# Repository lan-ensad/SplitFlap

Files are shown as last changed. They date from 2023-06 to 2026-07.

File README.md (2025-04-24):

# SplitFlap

Project : 

Installation for photographer [exhibition Isabelle Le Minh](https://galeriegaillard.com/exhibitions/206-isabelle-le-minh-postlude/overview/). Design & production by Olivier Bienz and Martin De Bie for six machines.

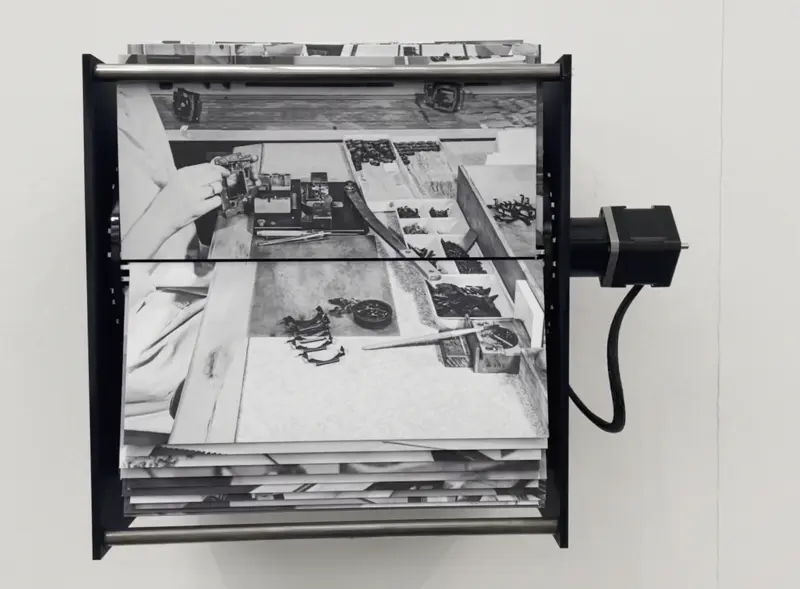
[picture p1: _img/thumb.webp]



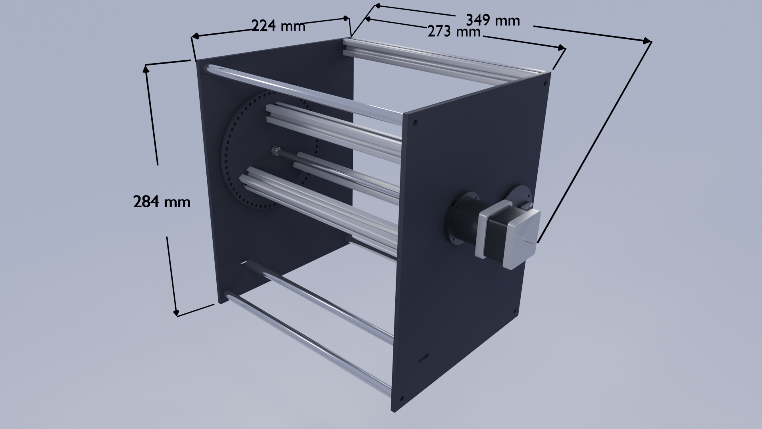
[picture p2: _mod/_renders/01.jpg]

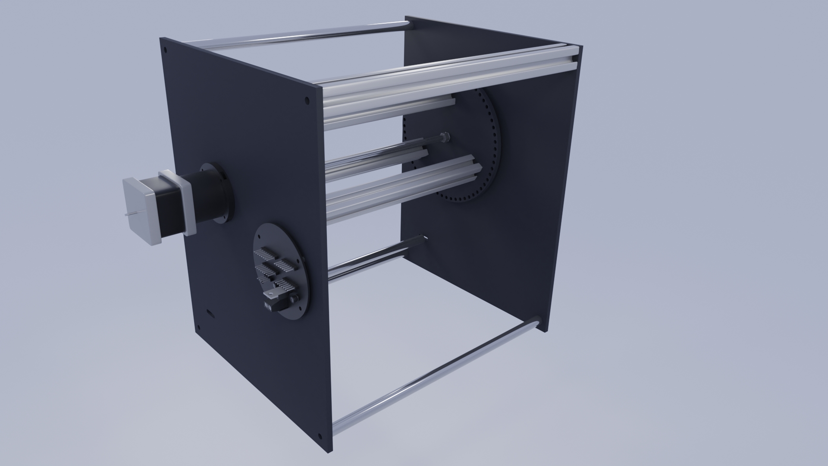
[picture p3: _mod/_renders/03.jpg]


## list

plans : .dxf et .svg \
`_mod/_exports/_plans`

pcb design : schematic, layout and gerber \
`_pcb/split_falp`

programme : \
two easy code to set motorSpeed and calibrate steps.

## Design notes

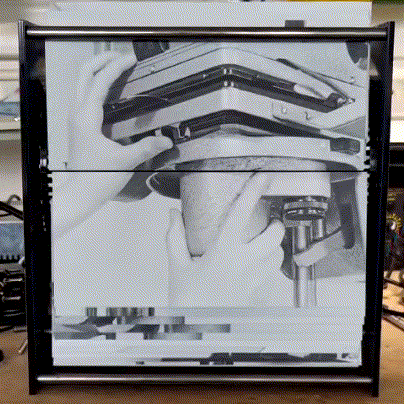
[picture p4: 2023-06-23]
output.gif

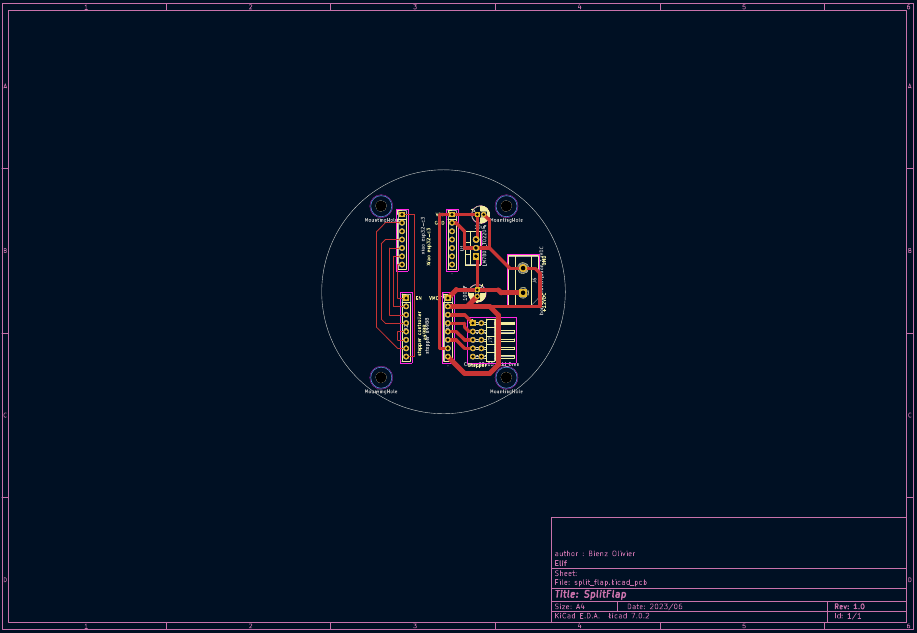
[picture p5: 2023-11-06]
pcb.png

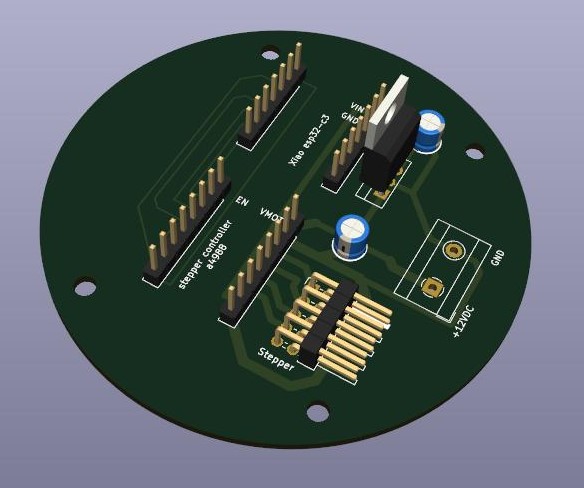
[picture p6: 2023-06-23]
_pcb/split_flap.jpg

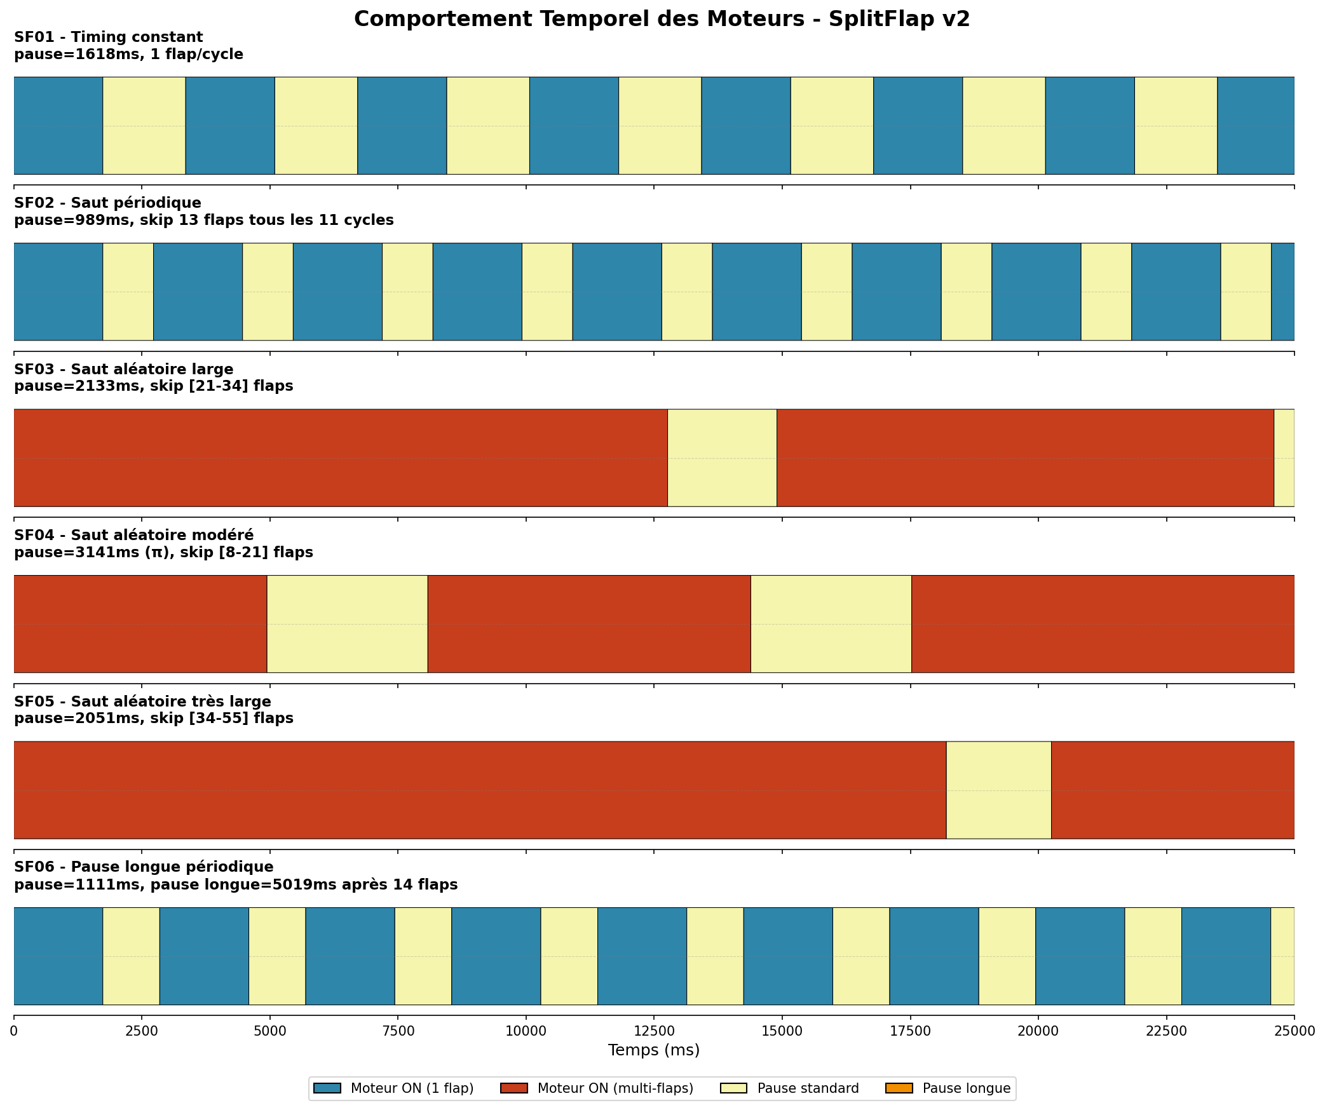
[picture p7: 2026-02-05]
_code/_v2/motor_timing_diagram.png

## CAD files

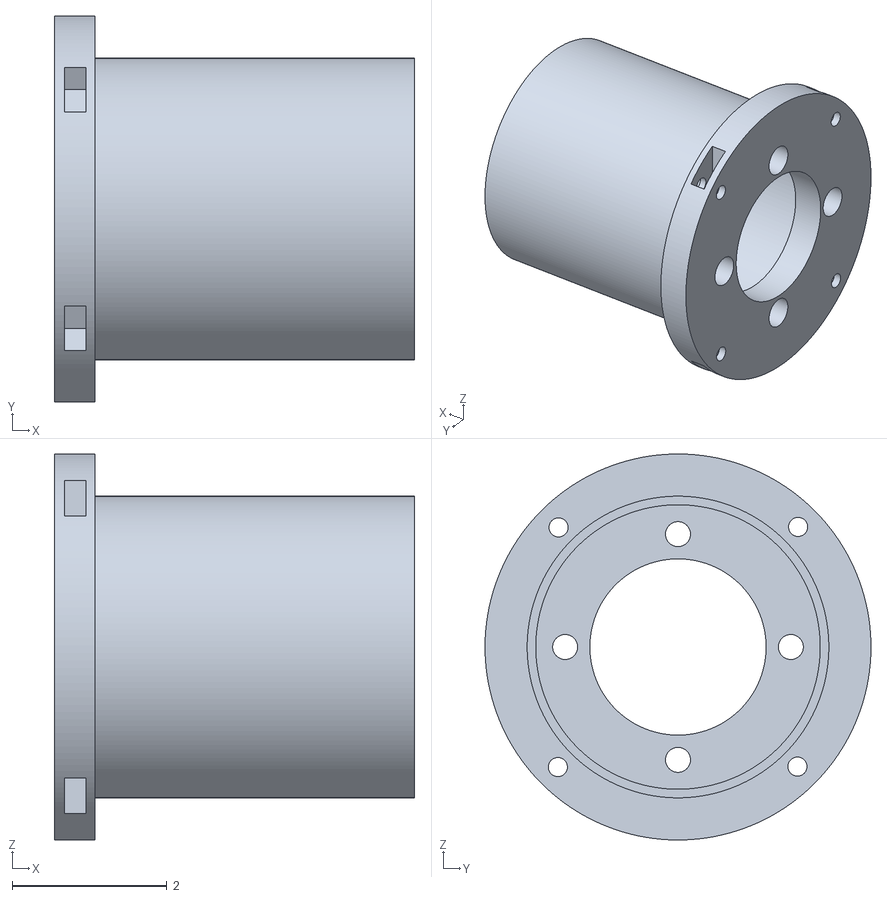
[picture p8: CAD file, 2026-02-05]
_mod/_exports/_3dprint/motor_mount.stl
4.65 x 4.98 x 4.98

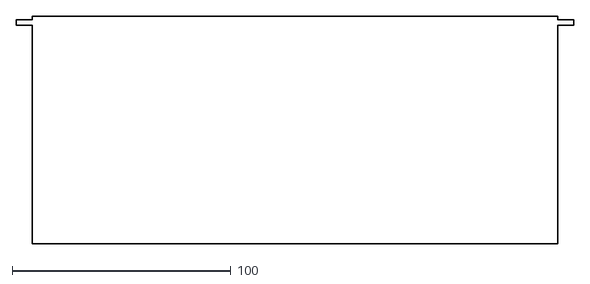
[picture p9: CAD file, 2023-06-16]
_mod/_exports/_plans/dxf/flap.dxf
255.0 x 104.0

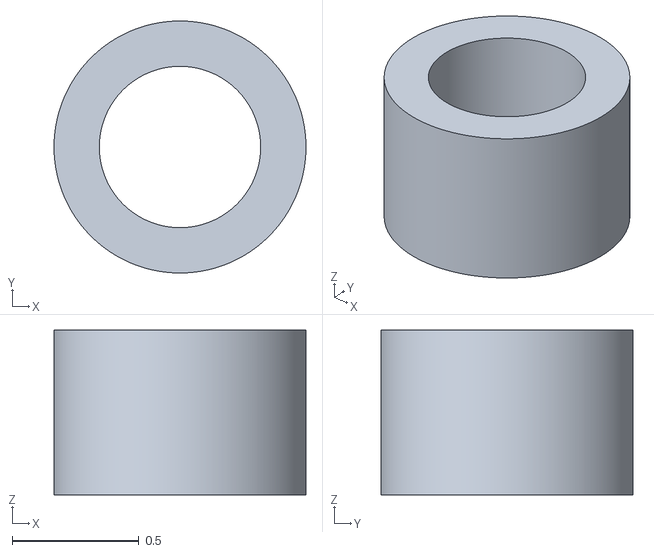
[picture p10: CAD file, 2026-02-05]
_mod/appendice.stl
0.994 x 0.994 x 0.65

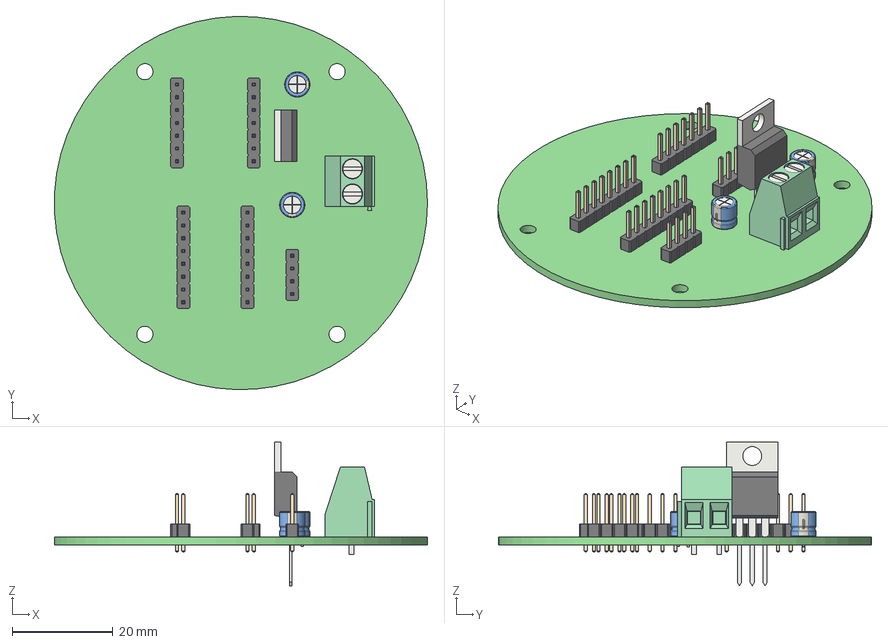
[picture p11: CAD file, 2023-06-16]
_pcb/split_flap/split_flap.step
73.9 x 74.0 x 28.5 mm
split_flap PCB

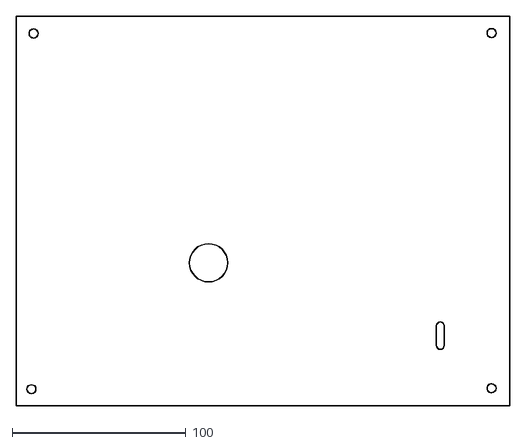
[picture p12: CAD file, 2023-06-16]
_mod/_exports/_plans/dxf/plate_L_10mm.dxf
283.9 x 224.0

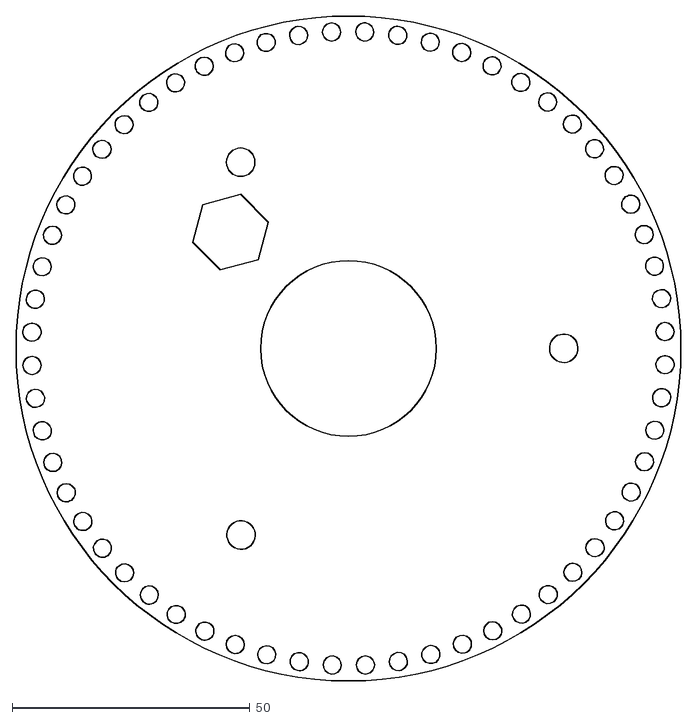
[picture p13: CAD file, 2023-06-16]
_mod/_exports/_plans/dxf/caroussel_mot.dxf
140.0 x 140.0

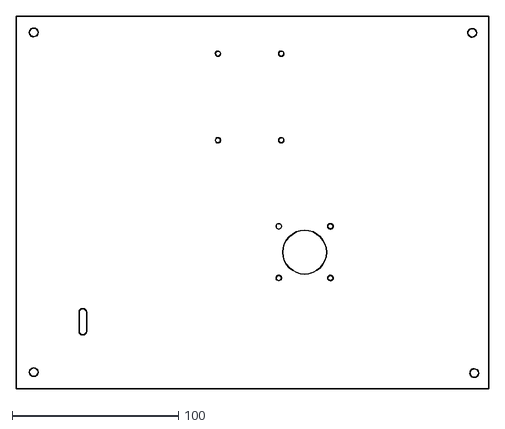
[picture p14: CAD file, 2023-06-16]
_mod/_exports/_plans/dxf/plate_R_10mm.dxf
284.0 x 224.0

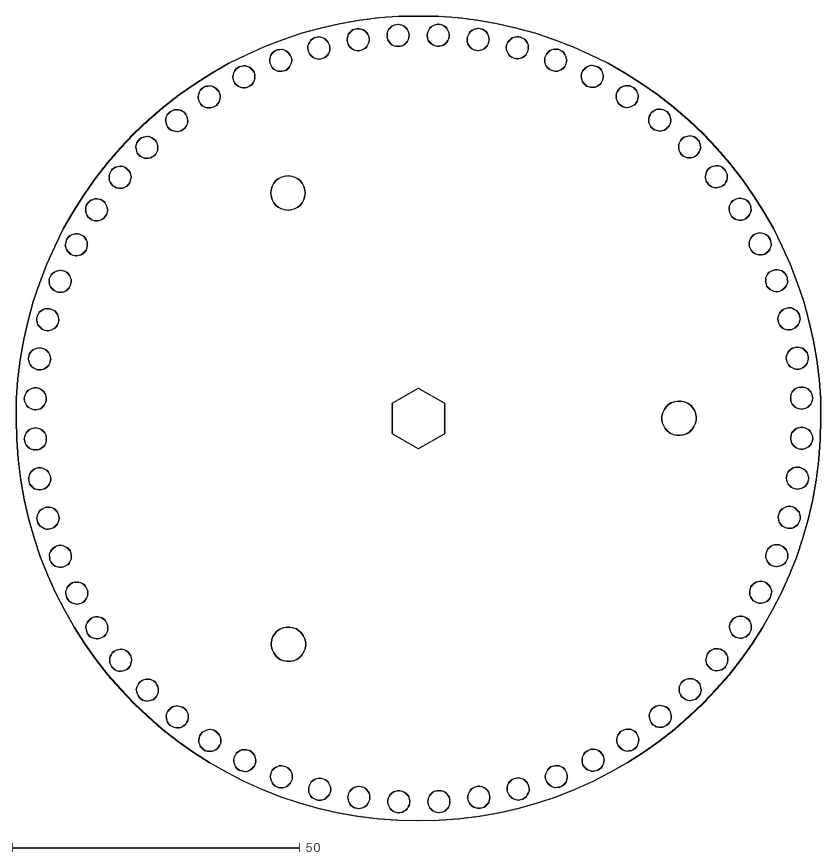
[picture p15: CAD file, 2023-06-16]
_mod/_exports/_plans/dxf/caroussel_bearing.dxf
140.0 x 140.0

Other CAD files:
_mod/flap_export_svg.blend

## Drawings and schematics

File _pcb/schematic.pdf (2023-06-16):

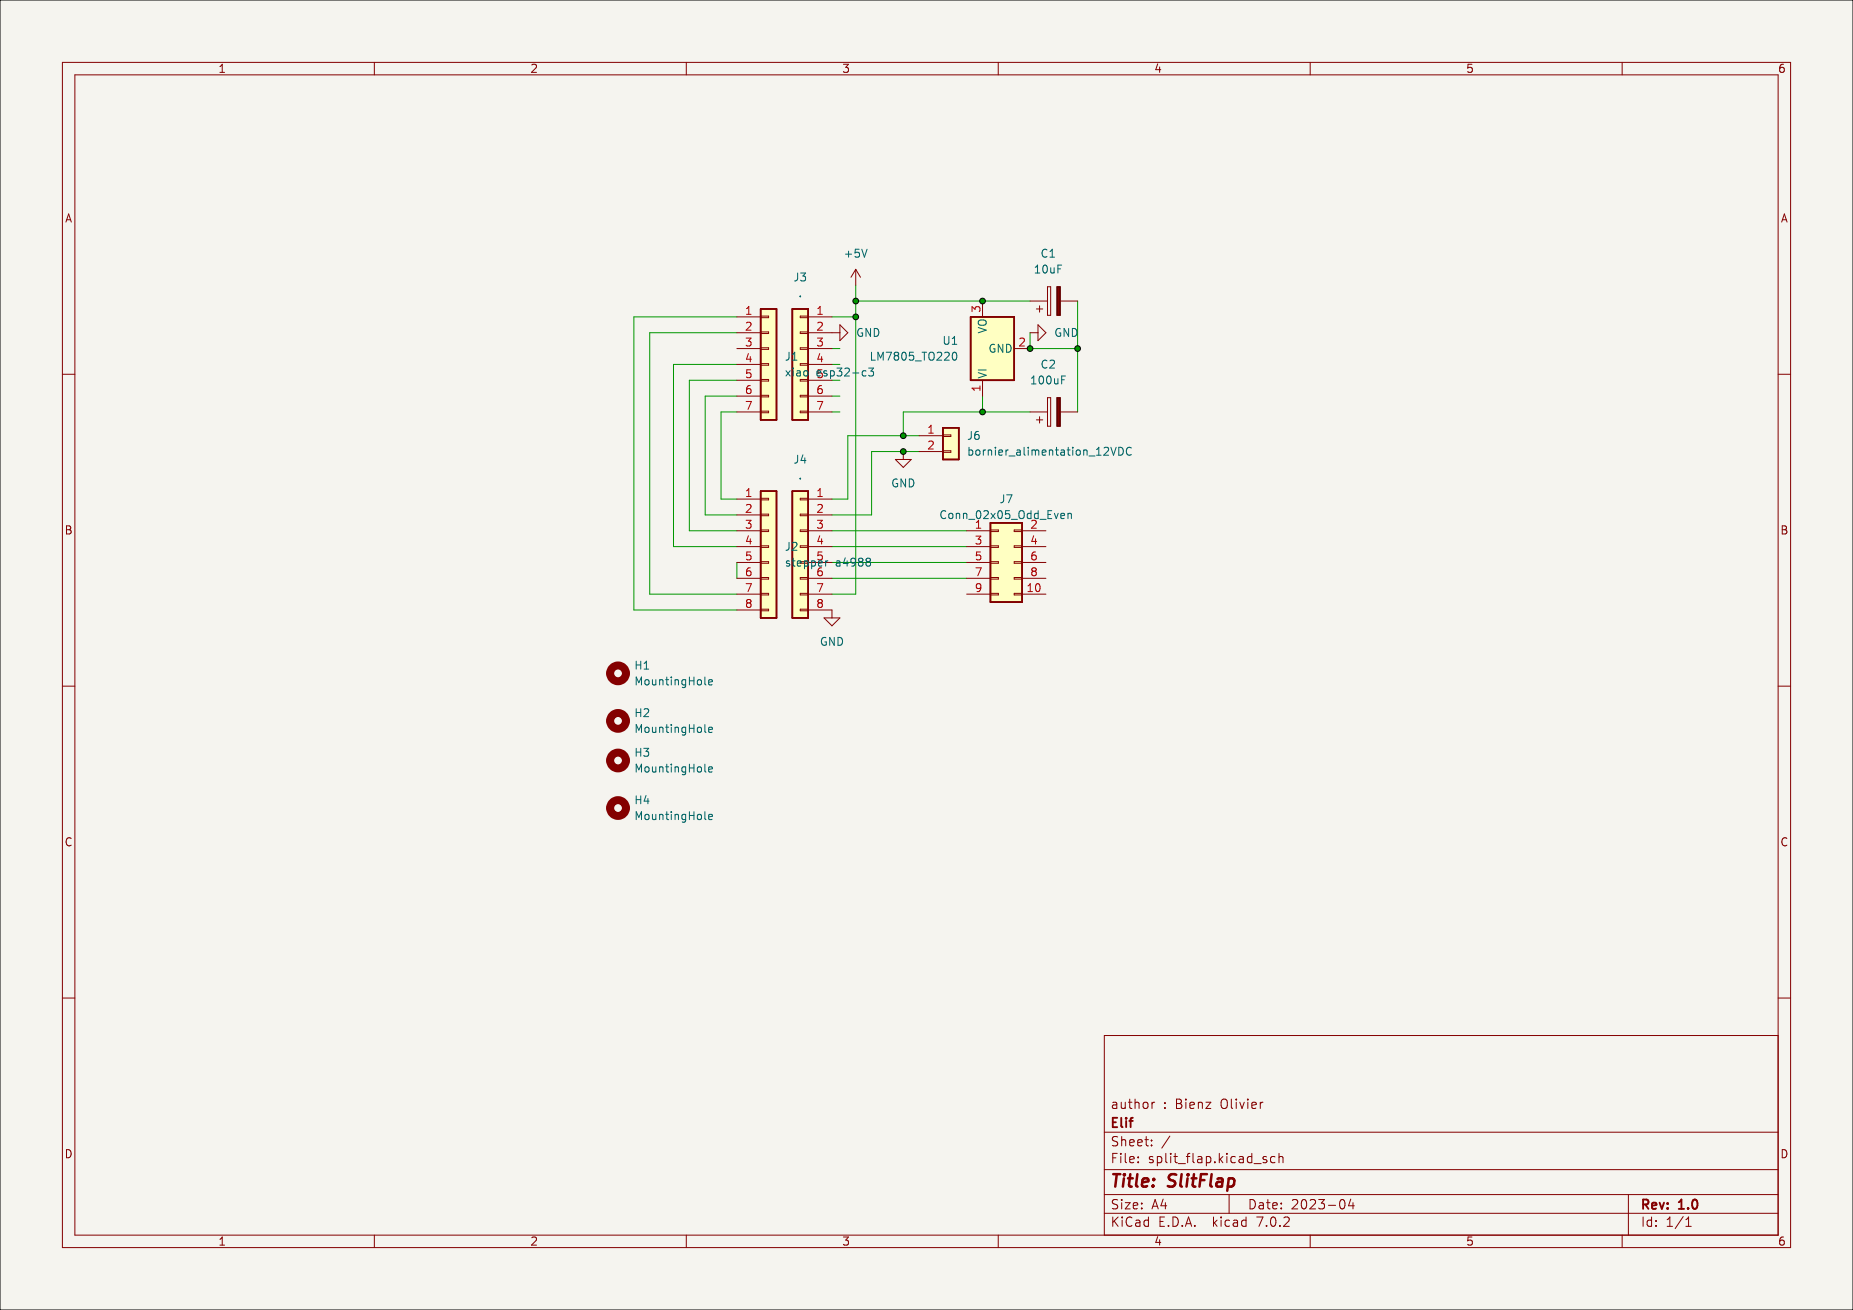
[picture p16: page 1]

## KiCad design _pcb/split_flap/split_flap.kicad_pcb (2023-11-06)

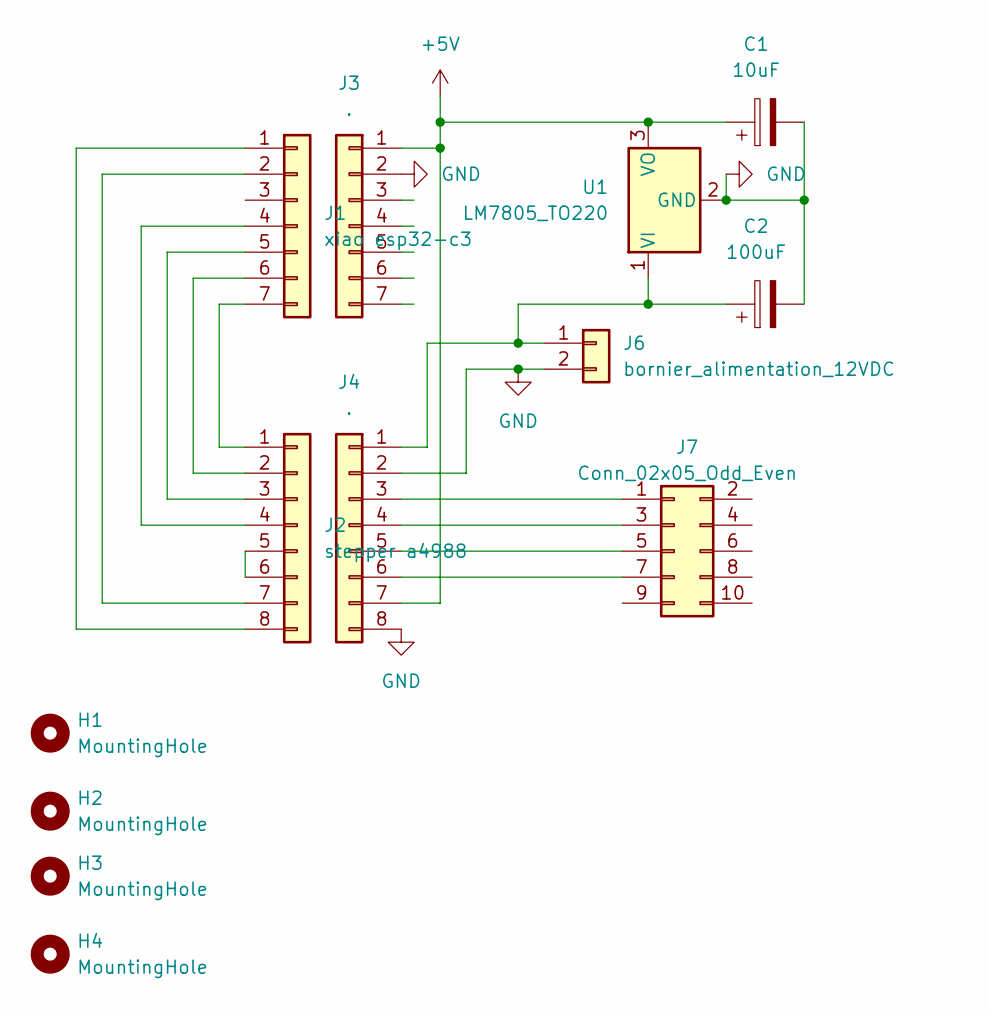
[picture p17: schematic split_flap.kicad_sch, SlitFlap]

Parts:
C1: 10uF; CP_Radial_D5.0mm_P2.00mm
C2: 100uF; CP_Radial_D5.0mm_P2.00mm
H1, H2, H3, H4: MountingHole; MountingHole_3.2mm_M3
J1: xiao esp32-c3; PinHeader_1x07_P2.54mm_Vertical
J2: stepper a4988; PinHeader_1x08_P2.54mm_Vertical
J3: .; PinHeader_1x07_P2.54mm_Vertical
J4: .; PinHeader_1x08_P2.54mm_Vertical
J6: bornier_alimentation_12VDC; TerminalBlock_MetzConnect_Type171_RT13702HBWC_1x02_P7.50mm_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
J7: Conn_02x05_Odd_Even; PinHeader_2x05_P2.54mm_Horizontal
U1: LM7805_TO220; TO-220-3_Vertical

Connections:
+5V: C1.1, J3.1, J4.7, U1.3 (VO)
GND: C1.2, C2.2, J3.2, J4.2, J4.8, J6.2, U1.2 (GND)
unnamed: J1.1, J2.8
unnamed: J1.2, J2.7
unnamed: J1.4, J2.4
unnamed: J1.5, J2.3
unnamed: J1.6, J2.2
unnamed: J1.7, J2.1
unnamed: J2.5, J2.6
unnamed: C2.1, J4.1, J6.1, U1.1 (VI)
unnamed: J4.3, J7.1
unnamed: J4.4, J7.3
unnamed: J4.5, J7.5
unnamed: J4.6, J7.7

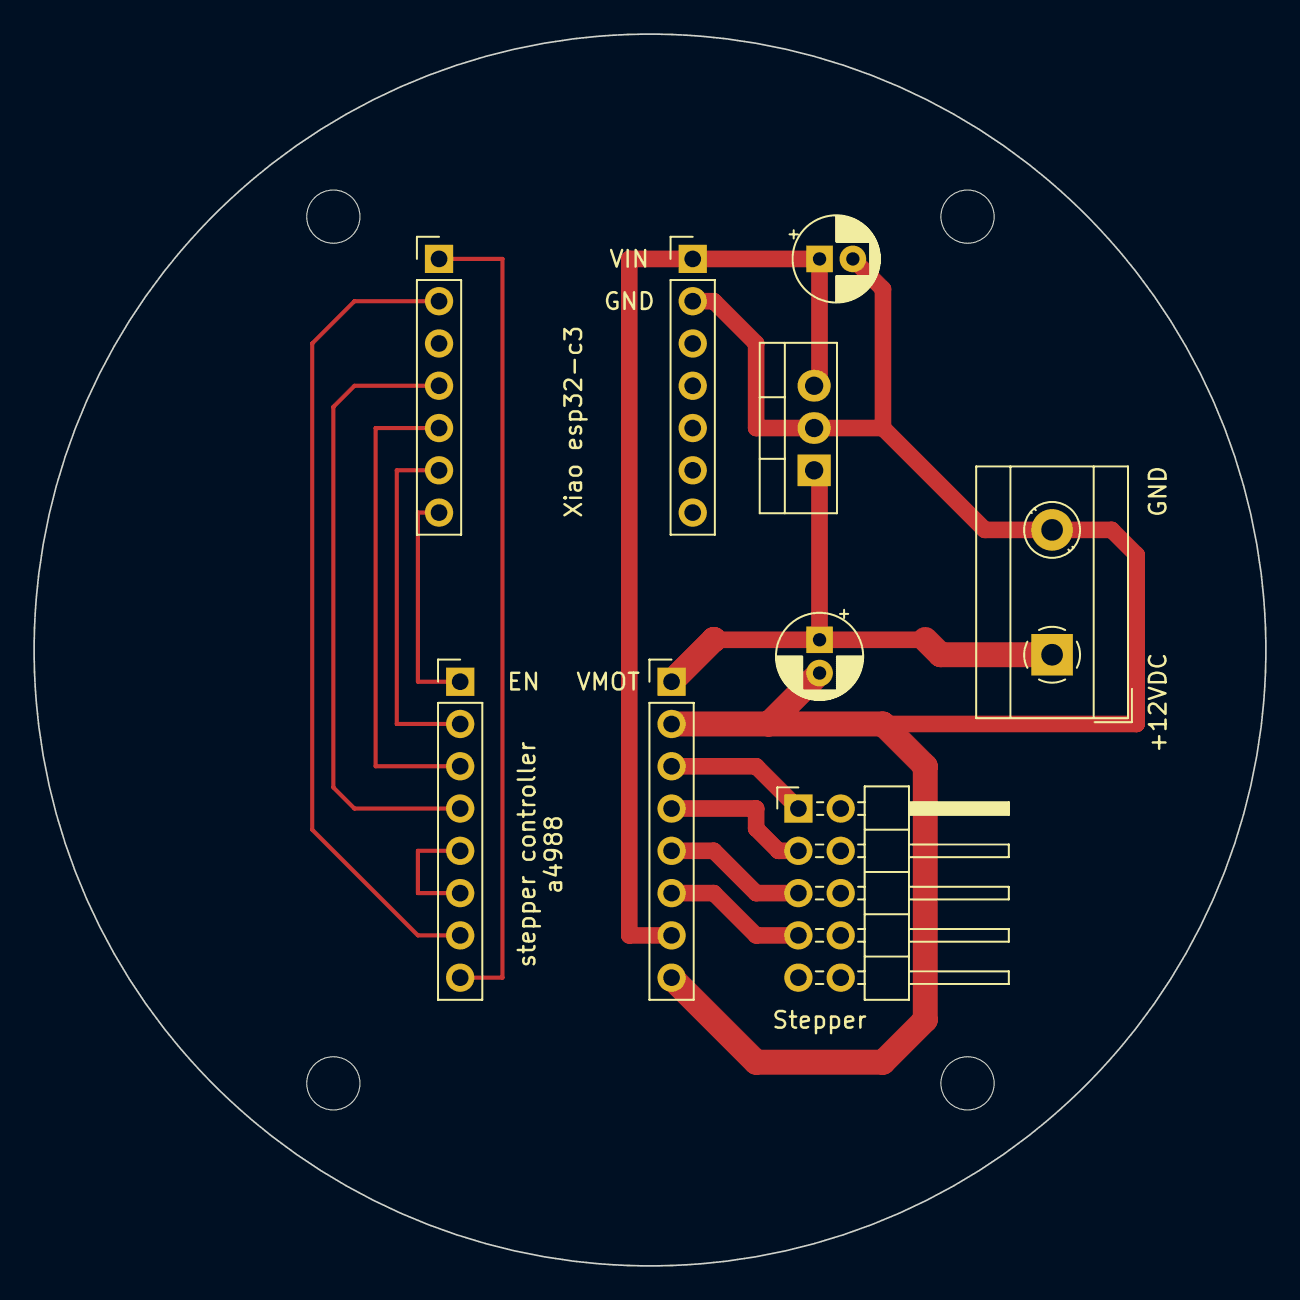
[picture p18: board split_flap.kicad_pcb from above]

Board: 2 copper layers, 74.0 x 74.0 mm, 13 parts (0 on the bottom side), 14 nets.

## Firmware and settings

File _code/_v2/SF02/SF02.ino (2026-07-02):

#include <AccelStepper.h>

//****************************************
//**************** A4988 *****************
// MS1    MS2   MS3   Microstep Resolution
//****************************************
// Low  | Low  | Low  |  Full step
// High | Low  | Low  |  Half step
// Low  | High | Low  |	 Quarter step
// High |	High | Low  |  Eighth step
// High |	High | High |	 Sixteenth step
//****************************************

//----------------------------------------------------------------------------
//                            INITIALISATION
//----------------------------------------------------------------------------
#define EN 21
#define MS1 7
#define MS2 6
#define MS3 5
#define STEP 3
#define DIR 2
#define MAXSPEED 1000 //Set maximum speed
#define ACCEL 450 //Set acceleration
#define DEFAULT_STP 135
AccelStepper stepper(AccelStepper::DRIVER, STEP, DIR);
int count = 0; //initialisation du nombre de flaps passé sur le programme


//----------------------------------------------------------------------------
//                           Variable à modifier
//----------------------------------------------------------------------------
int n_flaps_pass = 13;
int pause_standard = 989;
int stp = DEFAULT_STP;  //nb de steps/flap
int init_flaps = 30; //nb de flaps passés lors du démarrage
int pause_after = 10; //pass plus de flaps après n flaps
int timing = pause_standard; //temps entre deux flaps → l.65-69


//----------------------------------------------------------------------------
//                                SETUP INIT
//----------------------------------------------------------------------------
void setup() {
  Serial.begin(115200);

  pinMode(EN, OUTPUT);
  pinMode(MS1, OUTPUT);
  pinMode(MS2, OUTPUT);
  pinMode(MS3, OUTPUT);

  digitalWrite(EN, 0);  //0=ON ; 1=OFF
  digitalWrite(MS1, 1);
  digitalWrite(MS2, 1);
  digitalWrite(MS3, 0);

  stepper.setMaxSpeed(MAXSPEED);
  stepper.setAcceleration(ACCEL);
  stepper.setCurrentPosition(0);
  stepper.moveTo(DEFAULT_STP);
  stepper.setCurrentPosition(0);

  delay(1000); // Pause au démarrage
  if (stepper.distanceToGo() == 0) {
    stepper.moveTo(stepper.currentPosition() + DEFAULT_STP * init_flaps);  //To get flaps aligned
  }
  stepper.run();
  delay(2000); // Pause après l'initialisation
}


//----------------------------------------------------------------------------
//                                PINCIPAL LOOP
//----------------------------------------------------------------------------
void loop() {
  //--------------------------------------
  //Randomly add more steps to skip flaps
  //--------------------------------------
  if (count == pause_after) {
    stp = DEFAULT_STP*n_flaps_pass;
  } else {
    stp=DEFAULT_STP;
  }

  //--------------
  //  MAIN LOOP
  //  DO NOT MODIFY
  //  AFTER THIS LINE
  //--------------
  if (stepper.distanceToGo() == 0) {
    stepper.moveTo(stepper.currentPosition() + stp);
    delay(timing);
    count++;
  }
  if (count == pause_after+1) {
    count = 0;
  }
  stepper.run();
}
